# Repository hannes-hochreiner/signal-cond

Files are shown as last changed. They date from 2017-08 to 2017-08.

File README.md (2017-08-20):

# signal-cond
A simple signal conditioning circuit based on a [TI application note by Pete Wilson](http://www.ti.com/lit/an/sboa096/sboa096.pdf).

The circuit performs a linear transform of the voltage range from +/-30V to 0-3V.
I designed this circuit to safely use piezo-electric transducer that was specified for the range of -30 to +30V.

The board and the parts can be ordered from [AISLER](http://aisler.net/p/DYDJTZVP).

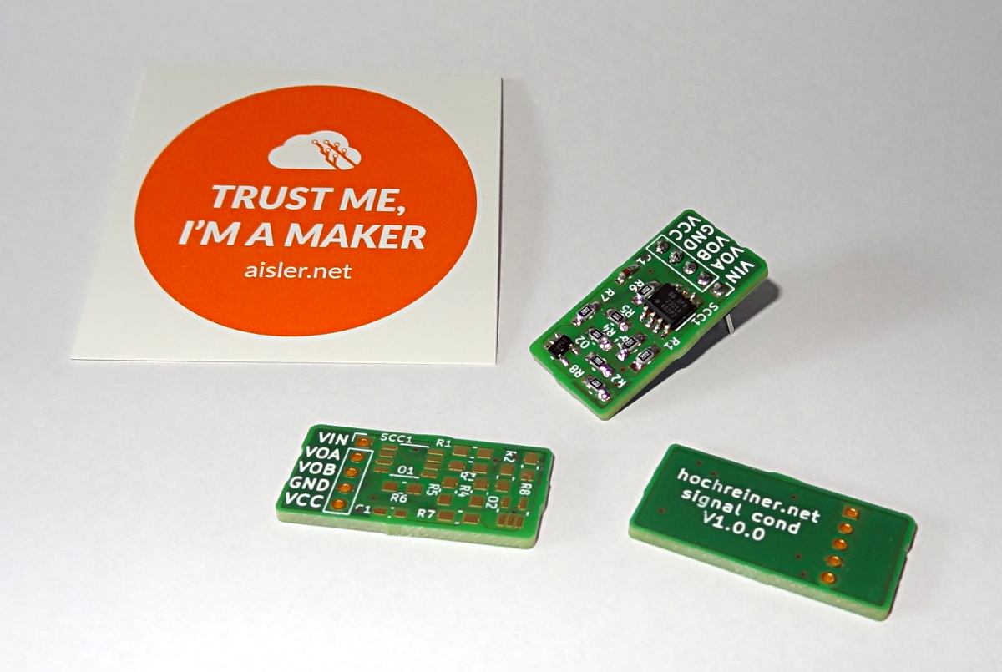
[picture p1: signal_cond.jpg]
bare and populated boards


The scaling factor of the circuit can be modified by changing the ratio of R1/R3 and R2/R4.
The offset can be set by changing Vref, which is dependent on the ratio of R7/R8.

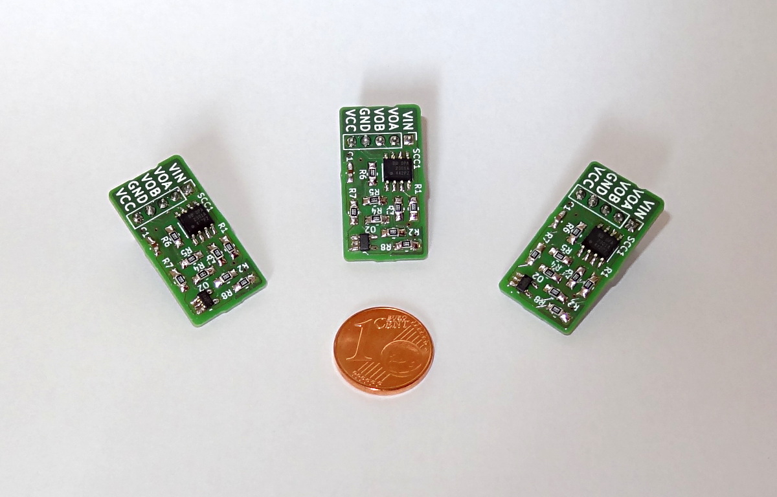
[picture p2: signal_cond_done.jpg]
completed modules


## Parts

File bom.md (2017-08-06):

| digi-key id | MPN | part | quantity | price |
| - | - | - | - | - |
| 296-26271-1-ND | OPA335AIDBVR | OPA355 | 1 | 2.45 |
| 296-33471-5-ND | OPA2301AID | OPA2301 | 1 | 2.43 |
| P20594CT-ND | ERJ-PB6B1001V | 1k Ohm | 2 | 0.30 |
| P20708CT-ND | ERJ-PB6B1002V | 10k Ohm | 4 | 0.30 |
| P20740CT-ND | ERJ-PB6B2002V | 20k Ohm | 2 | 0.30 |
| 311-1343-1-ND | CC0603ZRY5V9BB104 | 0.1µ F | 1 | 0.08 |
| S1012EC-05-ND | PREC005SAAN-RC | header straight 1x5 | 1 | 0.14 |
| | | | total | 7.50 |

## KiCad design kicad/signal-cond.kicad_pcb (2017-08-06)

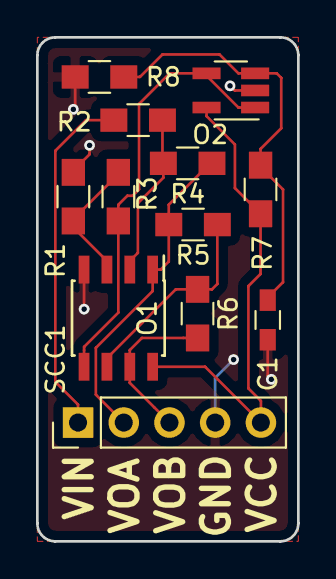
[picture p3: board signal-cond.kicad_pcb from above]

Board: 2 copper layers, 14.5 x 28.0 mm, 12 parts (0 on the bottom side), 10 nets.

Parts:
C1: 0.1µF; R_0603_HandSoldering
O1: TI-OPA2301-SO-8; SOIC-8_3.9x4.9mm_Pitch1.27mm
O2: TI-OPA335-SOT23-5; SOT-23-5_HandSoldering
R1, R2: 20k; R_0805_HandSoldering
R3, R4: 1k; R_0805_HandSoldering
R5, R6, R7, R8: 10k; R_0805_HandSoldering
SCC1: SIGNAL-COND-CONNECTOR; Pin_Header_Straight_1x05_Pitch2.54mm

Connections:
/VOUTA: O1.1, R4.1, R5.2, SCC1.2
/VOUTB: O1.7, R6.2, SCC1.3
/VREF: O1.5, O2.1, O2.4, R3.2
GND: C1.2, O1.4, O2.2, R1.2, R8.2, SCC1.4
unnamed: C1.1, O2.3, R7.2, R8.1
unnamed: O1.2, R2.1, R4.2
unnamed: O1.3, R1.1, R3.1
unnamed: O1.6, R5.1, R6.1
unnamed: R2.2, SCC1.1
VCC: O1.8, O2.5, R7.1, SCC1.5

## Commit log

2017-08-06 added simulation, circuit, and board
    [signal-cond.kicad_pcb, signal-cond.sch]
2017-08-06 added bom
2017-08-06 improved routing
    [signal-cond.kicad_pcb]
